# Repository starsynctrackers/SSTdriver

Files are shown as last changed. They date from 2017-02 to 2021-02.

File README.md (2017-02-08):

Schematic Based on the following:

1. BigEasyDriver_v12 by Brian Schmatz
    * [http://www.schmalzhaus.com/BigEasyDriver/](http://www.schmalzhaus.com/BigEasyDriver/)
    * License CC 3.0 Attribution US [https://creativecommons.org/licenses/by/3.0/us/](https://creativecommons.org/licenses/by/3.0/us/)
2. Metro THM+LDO Rv B by Limor Fried & KTOWN
    * [https://github.com/adafruit/Adafruit-METRO-328-PCB](https://github.com/adafruit/Adafruit-METRO-328-PCB)
> For more details, check out the product page at
>
>  * [https://www.adafruit.com/products/2466](https://www.adafruit.com/products/2466)
>
>Designed by Adafruit Industries.  
>Creative Commons Attribution, Share-Alike license, 
>Derivative of "Arduino UNO R3 Reference design" (http://www.arduino.cc/en/Main/ArduinoBoardUno)

### See Also ###
* "[Arduino From Scratch](https://rheingoldheavy.com/category/education/fundamentals/arduino-from-scratch-series/)" by RheinGold Heavy

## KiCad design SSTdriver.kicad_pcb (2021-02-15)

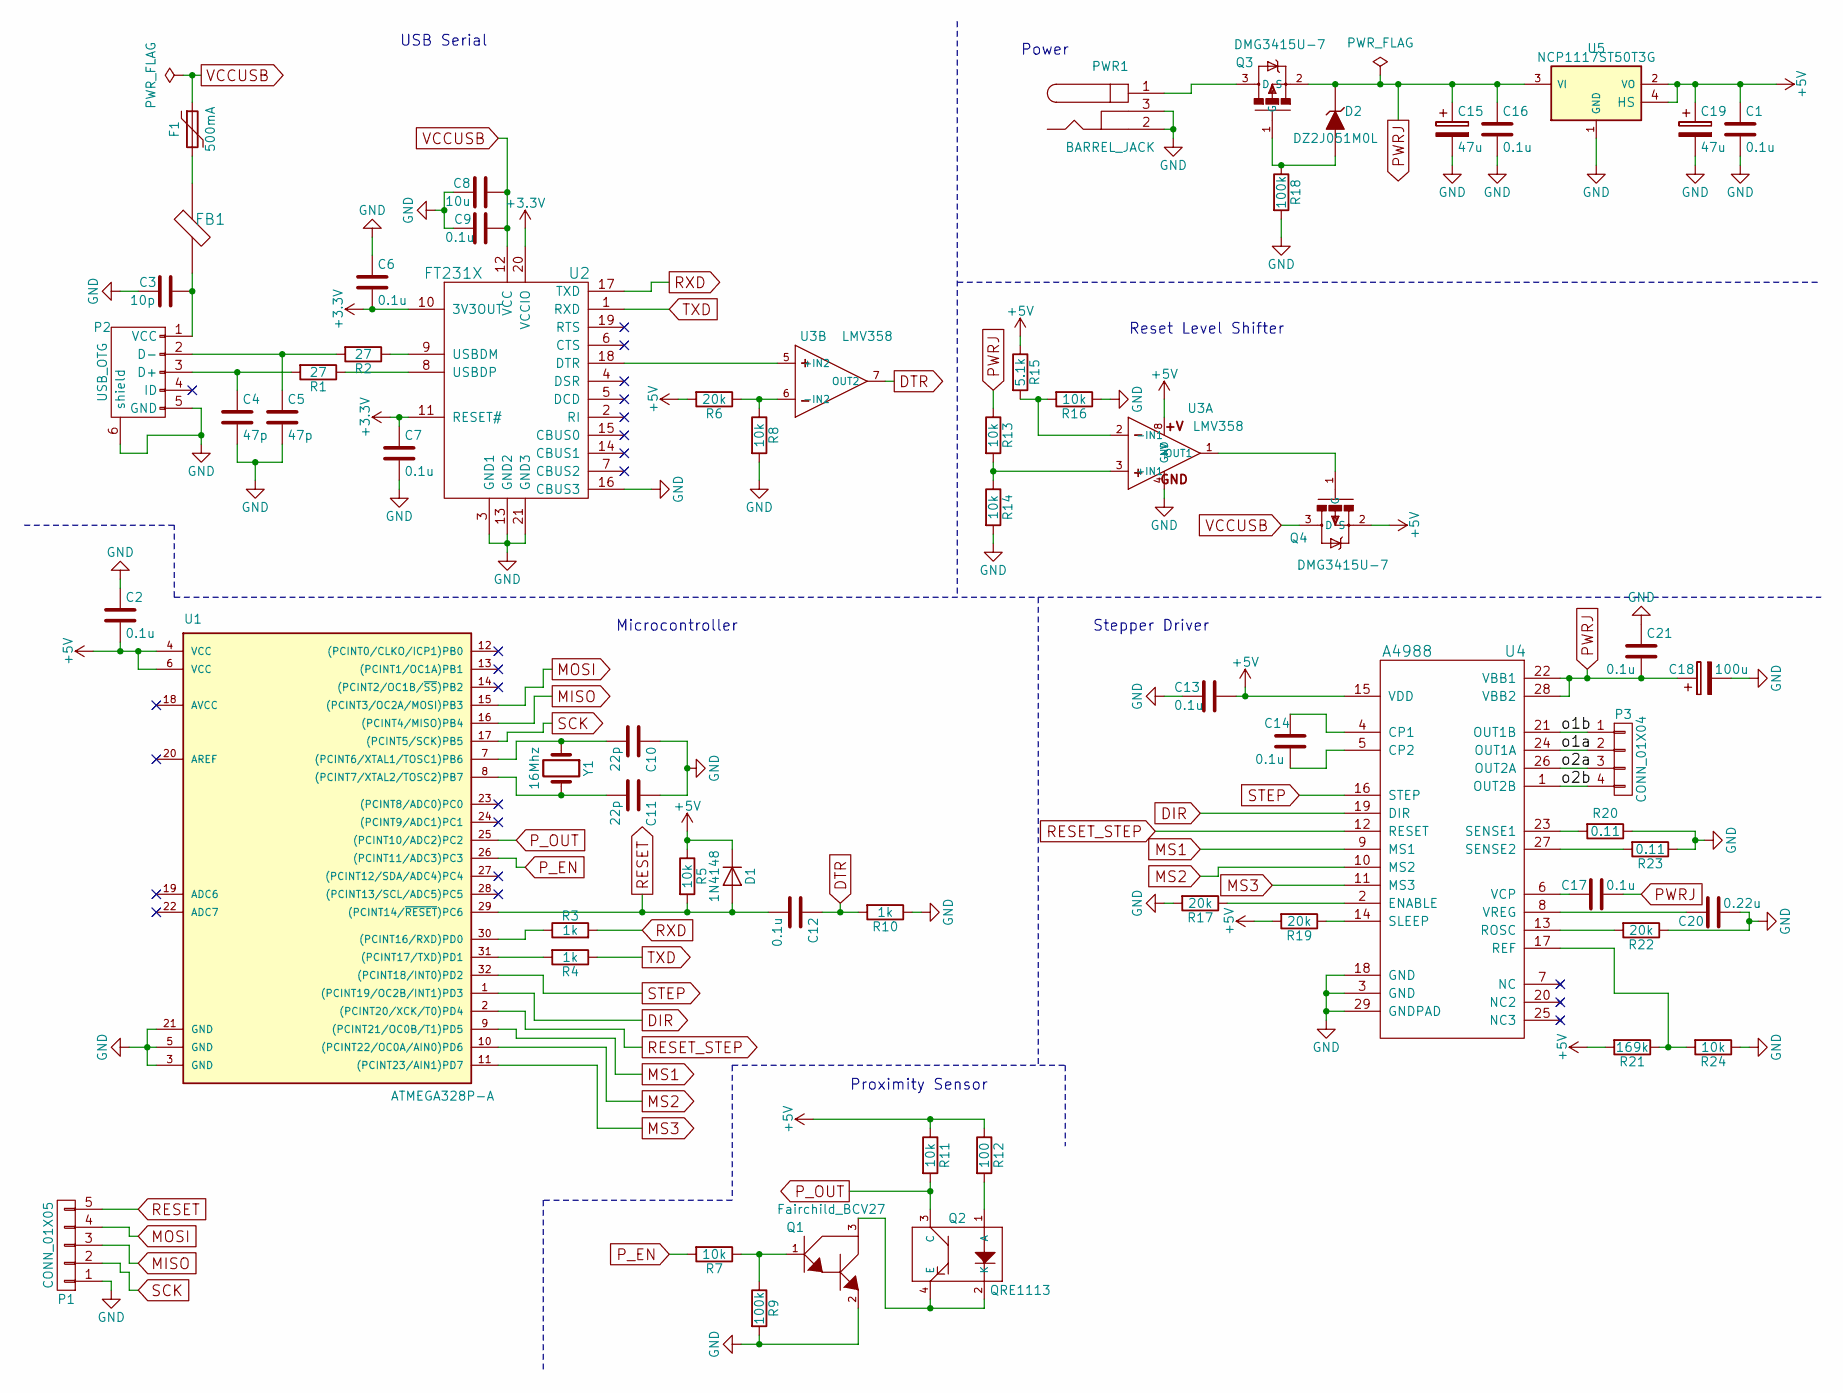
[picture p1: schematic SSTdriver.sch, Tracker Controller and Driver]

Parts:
C1, C2, C6, C7, C9, C12, C13, C14, C16, C17, C21: 0.1u; C_0603
C3: 10p; C_0603
C4, C5: 47p; C_0603
C8: 10u; C_0603
C10, C11: 22p; C_0603
C15, C19: 47u; CP_Elec_6.3x5.8
C18: 100u; c_elec_8x10
C20: 0.22u; C_0603
D1: 1N4148; SOD-323
D2: DZ2J051M0L; SOD-323
F1: 500mA; R_1812
FB1: ferrite_bead; R_0805
P1: CONN_01X05; 1X05_LOCK_LONGPADS
P2: USB_OTG; USB-MINIB
P3: CONN_01X04; 1X04_LOCK_LONGPADS
PWR1: BARREL_JACK; POWER_JACK_PTH
Q1: Fairchild_BCV27; SOT-23
Q2: QRE1113; SparkFun-QRE1113
Q3, Q4: DMG3415U-7; SOT-23
R1, R2: 27; R_0603
R3, R4, R10: 1k; R_0603
R5, R7, R8, R11, R13, R14, R16, R24: 10k; R_0603
R6, R17, R19, R22: 20k; R_0603
R9, R18: 100k; R_0603
R12: 100; R_0603
R15: 5.1k; R_0603
R20, R23: 0.11; R_0603
R21: 169k; R_0603
U1: ATMEGA328P-A; TQFP-32_7x7mm_Pitch0.8mm
U2: FT231X; QFN-20-1EP_4x4mm_Pitch0.5mm
U3: LMV358; TSSOP-8_3x3mm_Pitch0.65mm
U4: A4988; QFN-28-1EP_5x5mm_Pitch0.5mm
U5: NCP1117ST50T3G; SOT-223
Y1: 16Mhz; Crystal_HC49-SD_SMD

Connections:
+3V3: C6.2, C7.1, U2.10 (3V3OUT), U2.11 (RESET#), U2.20 (VCCIO)
+5V: C1.1, C2.2, C13.1, C19.1, D1.1 (K), Q4.2 (S), R5.1, R6.2, R11.1, R12.1, R15.1, R19.2, R21.2, U1.4 (VCC), U1.6 (VCC), U3.8 (+V), U4.15 (VDD), U5.2 (VO), U5.4 (HS)
/o1a: P3.2, U4.24 (OUT1A)
/o1b: P3.1, U4.21 (OUT1B)
/o2a: P3.3, U4.26 (OUT2A)
/o2b: P3.4, U4.1 (OUT2B)
DIR: U1.1 ((PCINT19/OC2B/INT1)PD3), U4.19 (DIR)
DTR: C12.1, R10.2, U3.7 (OUT2)
GND: C1.2, C2.1, C3.2, C4.2, C5.2, C6.1, C7.2, C8.1, C9.2, C10.1, C11.1, C13.2, C15.2, C16.2, C18.2, C19.2, C20.1, C21.1, P1.1, P2.5 (GND), P2.6 (shield), PWR1.2, PWR1.3, Q1.2, R8.2, R9.2, R10.1, R14.2, R16.1, R17.2, R18.2, R20.1, R22.1, R23.1, R24.1, U1.3 (GND), U1.5 (GND), U1.21 (GND), U2.3 (GND1), U2.13 (GND2), U2.16 (CBUS3), U2.21 (GND3), U3.4 (GND), U4.3 (GND), U4.18 (GND), U4.29 (GNDPAD), U5.1 (GND)
MISO: P1.3, U1.16 ((PCINT4/MISO)PB4)
MOSI: P1.4, U1.15 ((PCINT3/OC2A/MOSI)PB3)
MS1: U1.9 ((PCINT21/OC0B/T1)PD5), U4.9 (MS1)
MS2: U1.10 ((PCINT22/OC0A/AIN0)PD6), U4.10 (MS2)
MS3: U1.11 ((PCINT23/AIN1)PD7), U4.11 (MS3)
unnamed: C3.1, FB1.2, P2.1 (VCC)
unnamed: C4.1, P2.3 (D+), R1.2
unnamed: C5.1, P2.2 (D-), R2.2
unnamed: C10.2, U1.7 ((PCINT6/XTAL1/TOSC1)PB6), Y1.1
unnamed: C11.2, U1.8 ((PCINT7/XTAL2/TOSC2)PB7), Y1.2
unnamed: C14.1, U4.4 (CP1)
unnamed: C14.2, U4.5 (CP2)
unnamed: C17.2, U4.6 (VCP)
unnamed: C20.2, U4.8 (VREG)
unnamed: D2.2 (A), Q3.1 (G), R18.1
unnamed: F1.2, FB1.1
unnamed: PWR1.1, Q3.3 (D)
unnamed: Q1.1, R7.1, R9.1
unnamed: Q1.3, Q2.2 (K), Q2.4 (E)
unnamed: Q2.1 (A), R12.2
unnamed: Q4.1 (G), U3.1 (OUT1)
unnamed: R1.1, U2.8 (USBDP)
unnamed: R2.1, U2.9 (USBDM)
unnamed: R3.1, U1.30 ((PCINT16/RXD)PD0)
unnamed: R4.2, U1.31 ((PCINT17/TXD)PD1)
unnamed: R6.1, R8.1, U3.6 (-IN2)
unnamed: R13.2, R14.1, U3.3 (+IN1)
unnamed: R15.2, R16.2, U3.2 (-IN1)
unnamed: R17.1, U4.2 (ENABLE)
unnamed: R19.1, U4.14 (SLEEP)
unnamed: R20.2, U4.23 (SENSE1)
unnamed: R21.1, R24.2, U4.17 (REF)
unnamed: R22.2, U4.13 (ROSC)
unnamed: R23.2, U4.27 (SENSE2)
unnamed: U2.18 (DTR), U3.5 (+IN2)
PWRJ: C15.1, C16.1, C17.1, C18.1, C21.2, D2.1 (K), Q3.2 (S), R13.1, U4.22 (VBB1), U4.28 (VBB2), U5.3 (VI)
P_EN: R7.2, U1.26 ((PCINT11/ADC3)PC3)
P_OUT: Q2.3 (C), R11.2, U1.25 ((PCINT10/ADC2)PC2)
RESET: C12.2, D1.2 (A), P1.5, R5.2, U1.29 ((PCINT14/~RESET~)PC6)
RESET_STEP: U1.2 ((PCINT20/XCK/T0)PD4), U4.12 (RESET)
RXD: R3.2, U2.17 (TXD)
SCK: P1.2, U1.17 ((PCINT5/SCK)PB5)
STEP: U1.32 ((PCINT18/INT0)PD2), U4.16 (STEP)
TXD: R4.1, U2.1 (RXD)
VCCUSB: C8.2, C9.1, F1.1, Q4.3 (D), U2.12 (VCC)

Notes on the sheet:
Reset Level Shifter
Power
USB Serial
Microcontroller
Proximity Sensor
Stepper Driver

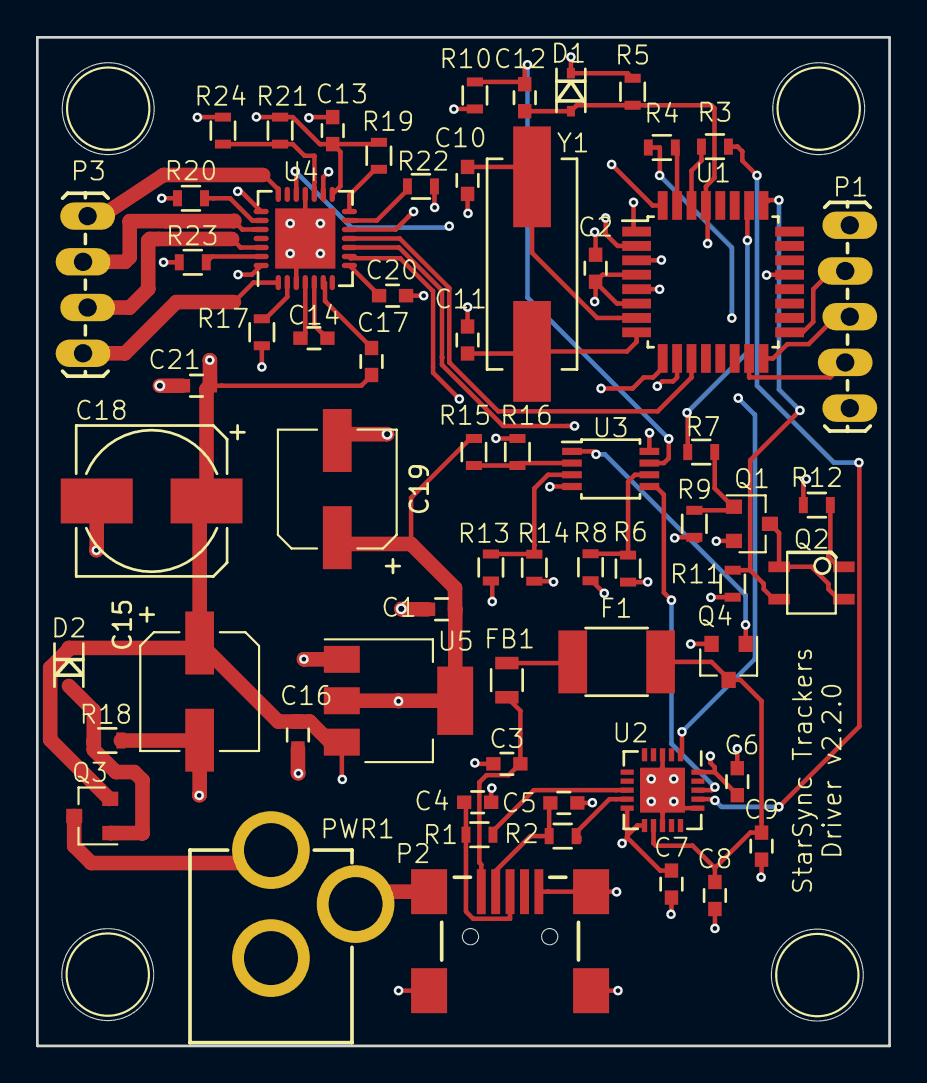
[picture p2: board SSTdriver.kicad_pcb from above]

Board: 4 copper layers, 47.3 x 56.0 mm, 63 parts (0 on the bottom side), 54 nets.

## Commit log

2017-01-29 First commit of new SSTdriver board.
    [SSTdriver.kicad_pcb, SSTdriver.sch]
2018-01-16 Fixed a trace clearance by usb interface chip.
    [SSTdriver.kicad_pcb, SSTdriver.sch]
